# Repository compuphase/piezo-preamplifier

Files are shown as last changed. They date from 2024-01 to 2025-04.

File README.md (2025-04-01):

# Piezo Pickup Preamplifier
These are simple designs for high impedance preamplifiers. They are intended for
piezo pickups, and in particular for piezo bridge pickups for (nylon-stringed)
guitars. There is a single-channel and a dual-channel design.

The designs are in KiCad. PDFs with the schematics, and the Gerber files for the
PCBs are also provided.

## Single channel
This circuit was built for use with a Shadow SH097 bridge pickup. The pickup has
a capacitance of 680pF. Yet, input impedance of this preamplifier is *only*
1M&Omega;, because the basses were already quite pronounced.

It is a pretty classic opamp circuit. Amplification is fixed at 1&times;
&mdash;the circuit is only to adapt the impedance (piezo bridge pickups are
pretty loud already). The main feature of the circuit is that it is compact,
and especially narrow. The idea is to fit this preamplifier into a slot
immediately below the pickup.

The PDF with the schematic also shows the wiring for a TRS socket and battery;
these are not on the PCB, and technically not part of the circuit). The main
idea of the wiring is that the battery is connected only when the jack plug is
inserted. When the plug is pulled out of the instrument, the battery is disconnected.

## Dual channel
This circuit was built for the ARTEC PG-333 bridge pickup. The pickup connects two
piezo bridge pickups in parallel, where each pickup covers only three strings. For
use with this preamplifier, the two piezo segments have to be separated, and each
connected to a separate input of the preamplifer. Input impedance for each channel
is roughly 2M&Omega;.

I measured one of the piezo segments to have a capacitance of 580pF and the other
as 970pF &mdash;to my surprise. This being the case, you will want to position
the 580pF segment at the treble side, and the 970pF segment at the bass side of
the bridge.

The dual-channel circuit has two independent impedance converters, and a third
preamplifier to mix the outputs of the first stages. The balance of the "treble"
side relative to the "bass" side, can be adjusted with a trimmer pot.

The preamplifier has a "bass boost" filter that boosts the frequencies below
roughly 250 Hz by roughly 5 dB. The resonance chamber of a classical guitar has
a main resonant frequency at around 200 to 250 Hz, which is what the bass boost
emulates.

---

Copyright 2023-2025, CompuPhase, Thiadmer Riemersma<br>
This work is licensed under a Creative Commons Attribution-NonCommercial-ShareAlike 4.0 International License (https://creativecommons.org/licenses/by-nc-sa/4.0/).

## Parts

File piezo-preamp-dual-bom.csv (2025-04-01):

Reference | Value | Footprint | Qty | ProductNumber
C1,C2,C5 | 220n | VisualPlace:0603 | 3
C3,C4 | 68p | VisualPlace:0603 | 2
C6 | 22n | VisualPlace:0603 | 1
C7,C9,C10 | 1u | VisualPlace:0603 | 3
C8 | 4u7 | VisualPlace:0805 | 1
R1,R2 | 2M2 | VisualPlace:0603 | 2
R3,R4,R5,R6,R10,R11,R12,R15 | 100k | VisualPlace:0603 | 8
R7,R8 | 470k | VisualPlace:0603 | 2
R9,R13 | 22k | VisualPlace:0603 | 2
RV2 | 20k | TrimPots:TC42 | 1 | 3312J-1-203E
U1,U2,U3 | OPA323 | VisualPlace:SOT353 | 3 | OPA323IDCKR

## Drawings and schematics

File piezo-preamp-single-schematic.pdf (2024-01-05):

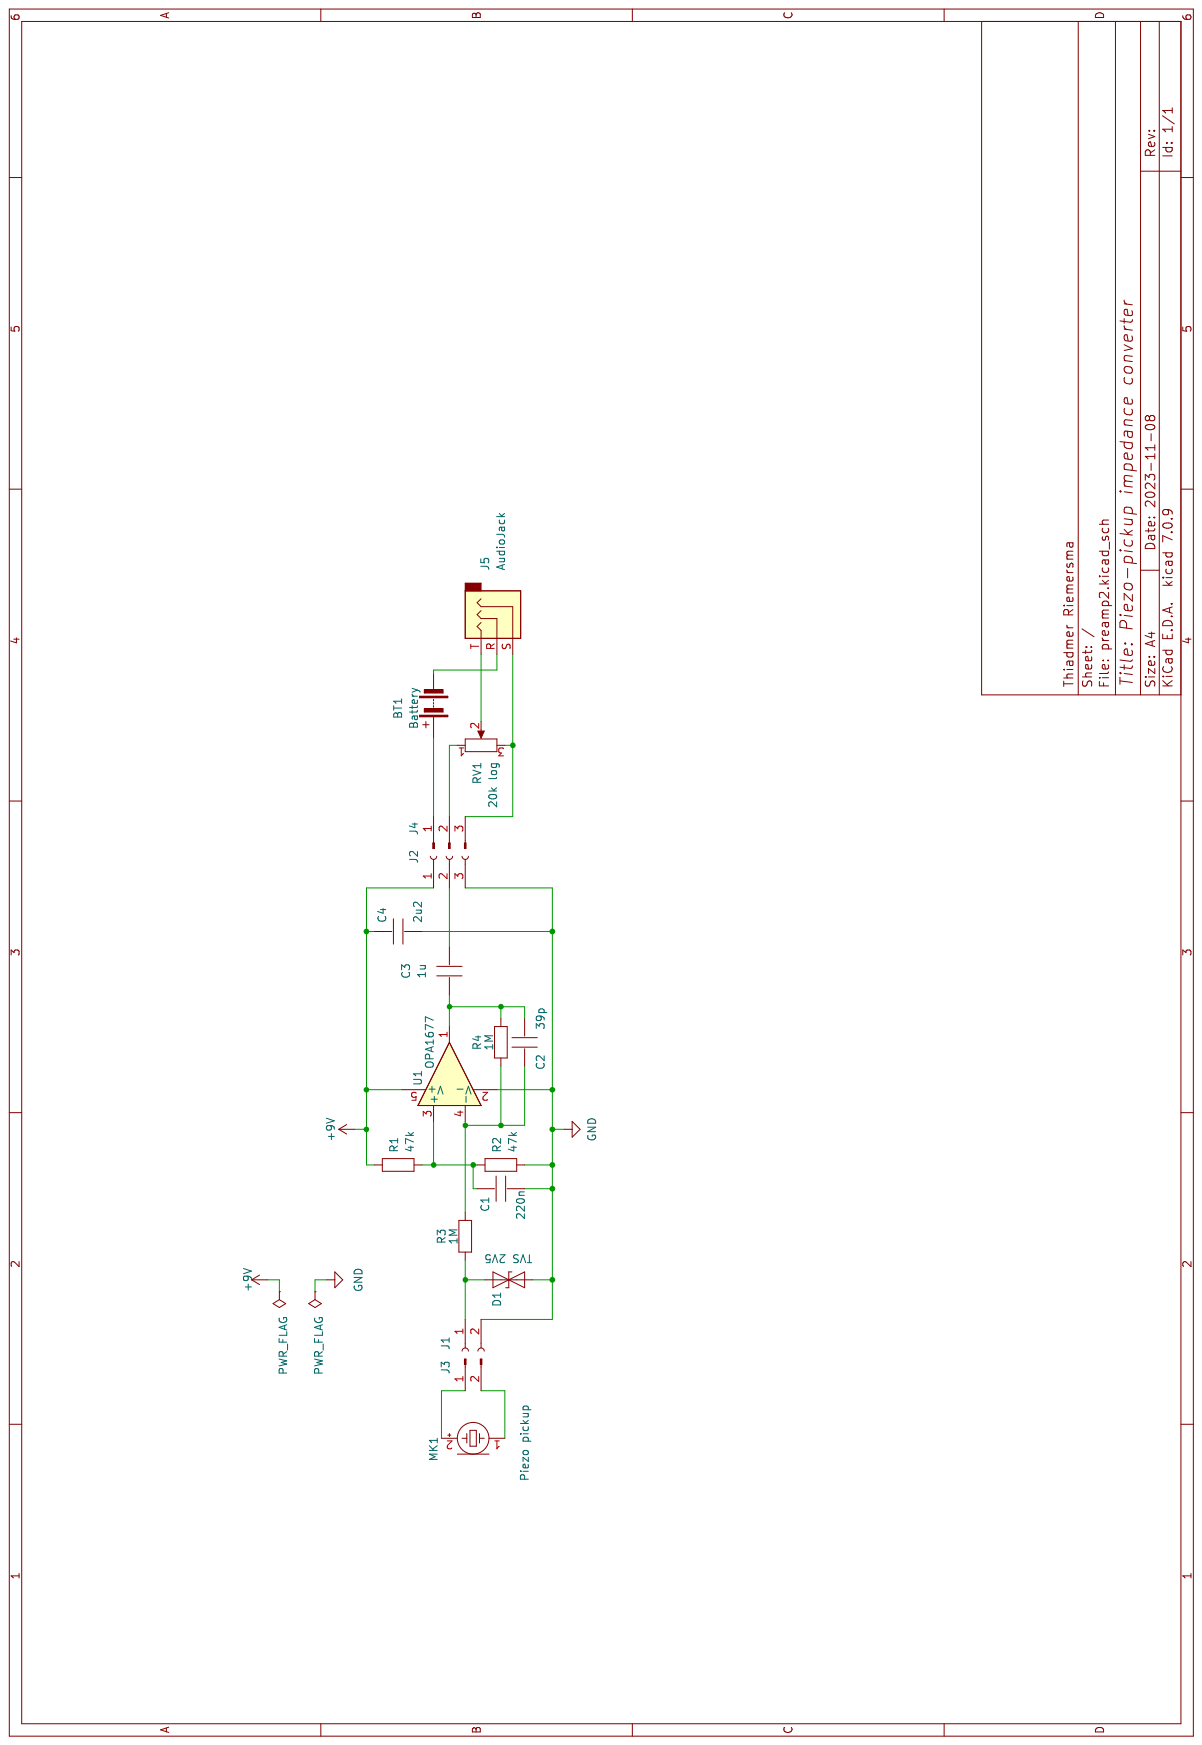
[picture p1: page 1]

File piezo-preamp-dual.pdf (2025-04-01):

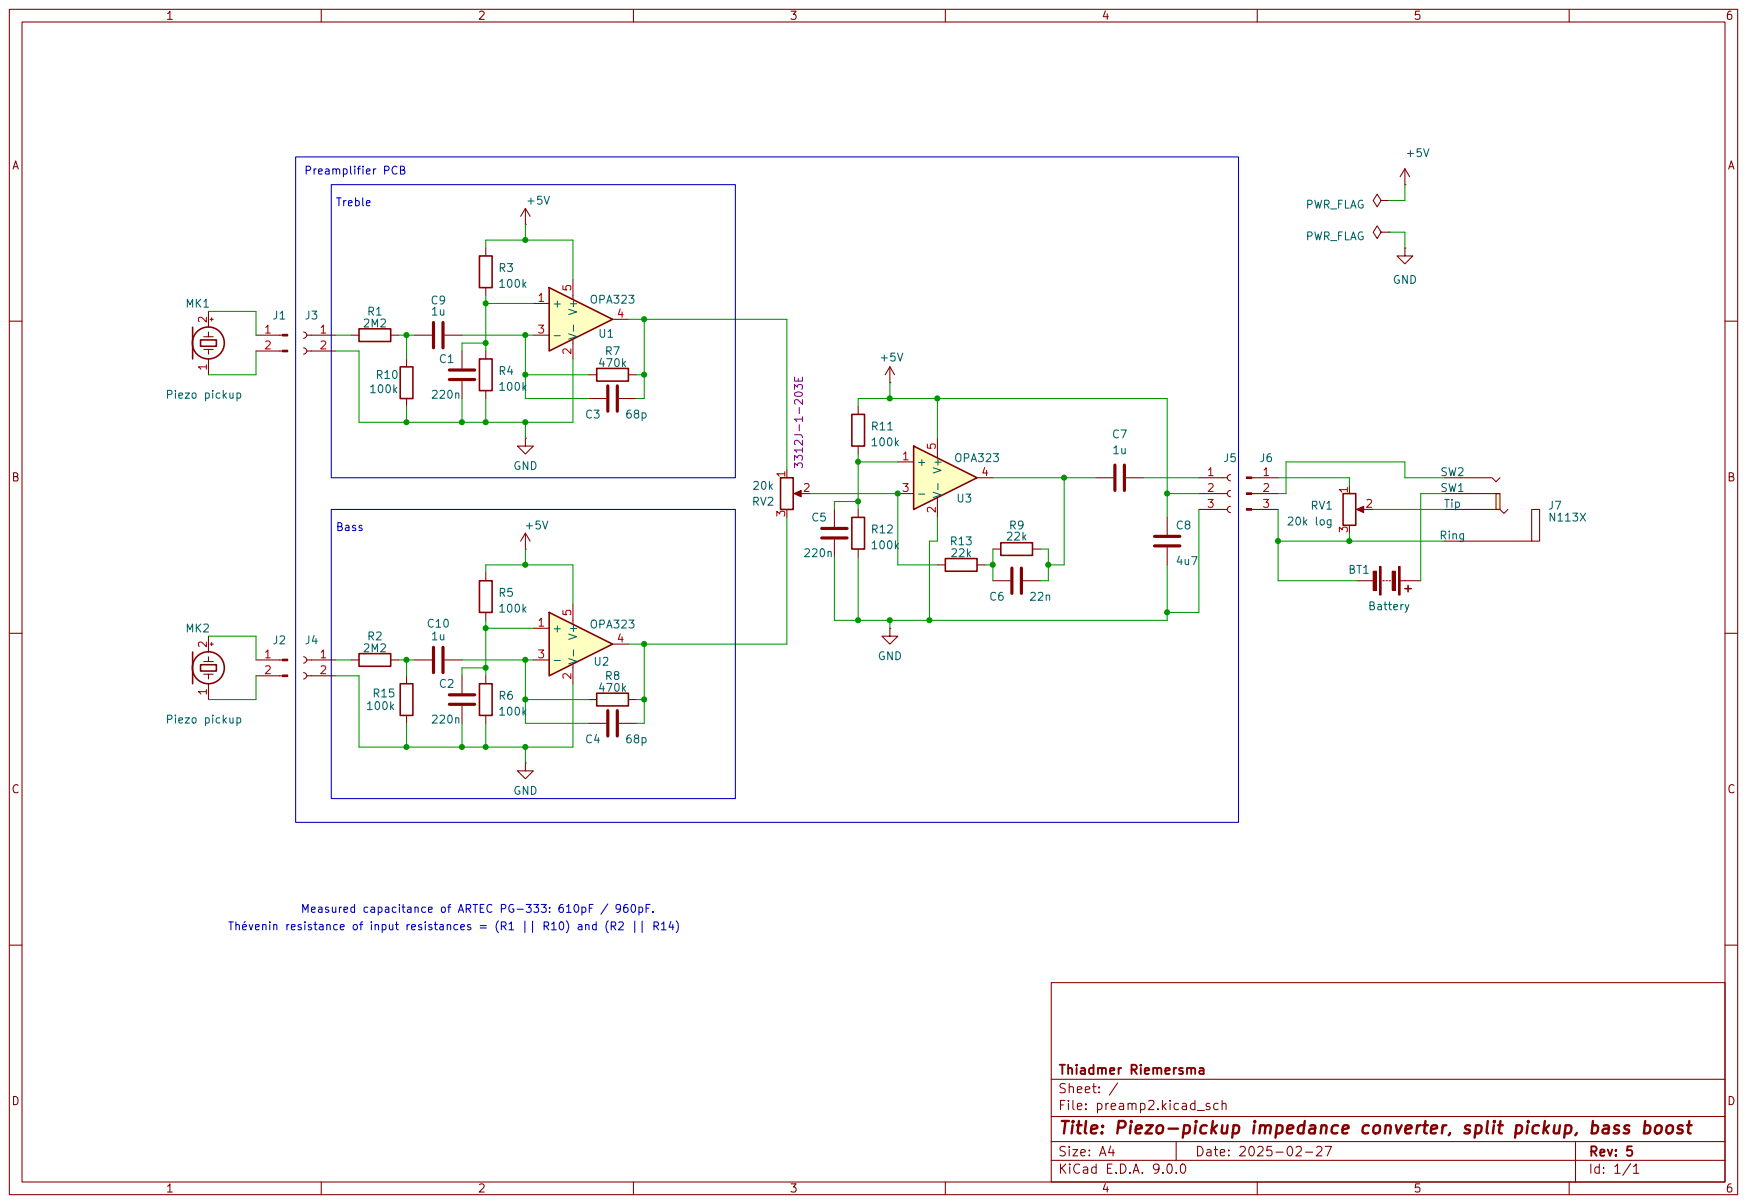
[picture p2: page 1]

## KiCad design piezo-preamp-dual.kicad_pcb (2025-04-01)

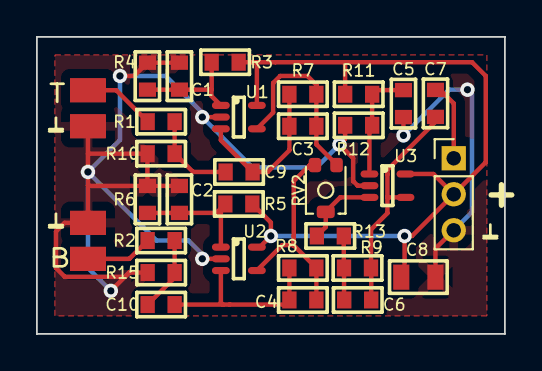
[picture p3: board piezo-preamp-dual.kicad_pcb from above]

Board: 2 copper layers, 26.0 x 16.5 mm, 31 parts (0 on the bottom side), 17 nets.

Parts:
C1, C2, C5: 220n; 0603
C3, C4: 68p; 0603
C6: 22n; 0603
C7: 1u; 0603
C8: 4u7; 0805
C9, C10: 100k; 0603
J3, J4: piezo; PinHeader_1x02_P2.00mm_Vertical
J5: output; PinHeader_1x03_P2.00mm_Vertical
R1, R2: 2M2; 0603
R3, R4, R5, R6, R10, R11, R12, R15: 100k; 0603
R7, R8: 470k; 0603
R9, R13: 22k; 0603
RV2: 20k; TC42
U1, U2, U3: OPA323; SOT353

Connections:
+5V: C8.1, J5.2, R3.1, R5.1, R11.1, U1.5 (V+), U2.5 (V+), U3.5 (V+)
GND: C1.2, C2.2, C5.2, C8.2, J3.2, J4.2, J5.3, R4.2, R6.2, R10.2, R12.2, R15.2, U1.2 (V-), U2.2 (V-), U3.2 (V-)
unnamed: C3.2, R7.2, RV2.1, U1.4
unnamed: C4.2, R8.2, RV2.3, U2.4
unnamed: C6.1, R9.1, R13.2
unnamed: C6.2, C7.1, R9.2, U3.4
unnamed: J3.1, R1.1
unnamed: J4.1, R2.1
unnamed: C7.2, J5.1
unnamed: C9.1, R1.2, R10.1
unnamed: C10.1, R2.2, R15.1
unnamed: C1.1, R3.2, R4.1, U1.1 (+)
unnamed: C3.1, C9.2, R7.1, U1.3 (-)
unnamed: C2.1, R5.2, R6.1, U2.1 (+)
unnamed: C4.1, C10.2, R8.1, U2.3 (-)
unnamed: C5.1, R11.2, R12.1, U3.1 (+)
unnamed: R13.1, RV2.2, U3.3 (-)

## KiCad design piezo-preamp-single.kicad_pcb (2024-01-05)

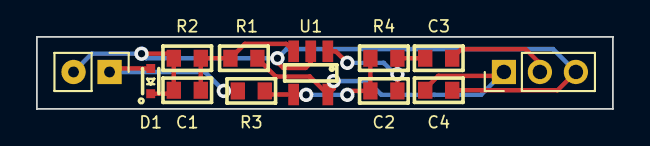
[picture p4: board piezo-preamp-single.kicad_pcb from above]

Board: 2 copper layers, 32.0 x 4.0 mm, 12 parts (0 on the bottom side), 7 nets.

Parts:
C1, C3, C4: 1u; 0603
C2: 10p; 0603
D1: TVS 6V; SOD523
J1: piezo; PinHeader_1x02_P2.00mm_Vertical
J2: output; PinHeader_1x03_P2.00mm_Vertical
R1, R2: 22k; 0603
R3, R4: 820k; 0603
U1: OPA1677; SOT23-5

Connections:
+9V: C4.1, J2.1, R1.1, U1.5 (V+)
GND: C1.2, C4.2, D1.1 (A1), J1.2, J2.3, R2.2, U1.2 (V-)
unnamed: C2.2, C3.1, R4.2, U1.1
unnamed: D1.2 (A2), J1.1, R3.1
unnamed: C3.2, J2.2
unnamed: C1.1, R1.2, R2.1, U1.3 (+)
unnamed: C2.1, R3.2, R4.1, U1.4 (-)

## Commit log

2023-12-25 Add PDF of schematic.
2023-12-27 Tweaked some component values.
    [preamp2.kicad_sch]
2023-12-27 Tweaked some component values, again.
    [preamp2.kicad_sch]
2023-12-27 Update README.md
    Correction in the description for the input impedance and frequency cut-off point.
2024-01-05 A few more tweaks in components, after more measurements.
    [preamp2.kicad_pcb, preamp2.kicad_sch]
2024-01-19 Rename design files for single-channel amplifier.
    [piezo-preamp-single.kicad_pcb, piezo-preamp-single.kicad_sch]
2024-01-19 Rename Gerber files for single-channel piezo amplifier.
    [piezo-preamp-job.gbrjob, piezo-preamp-single-B_Cu.gbr, piezo-preamp-single-B_Mask.gbr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]
2024-01-19 Add dual-channel piezo preamplifier.
    [piezo-preamp-dual-B_Cu.gbr, piezo-preamp-dual-B_Mask.gbr, piezo-preamp-dual-Edge_Cuts.gbr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]
2024-01-31 The TVS diodes were removed from the "dual-channel" design. The PCB is slighly smaller as a result.
    The parasitic capacitance of the TVS diodes had a negative effect on the sound. In addition, they were redundant; the inputs of the OPA1677 are already protected against overvoltage, so the 1 MOhm re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
    [piezo-preamp-dual-B_Cu.gbr, piezo-preamp-dual-B_Mask.gbr, piezo-preamp-dual-Edge_Cuts.gbr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]
2024-07-14 Added bass-boost filter (dual-channel preamp only). Added Bill-Of-Materials file. Fixed PDF of the schematic (turned out to be unreadable).
    [piezo-preamp-dual-bom.csv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]
2025-04-01 Reduce (peak) voltage of the piezo pick-ups, to avoid saturatating the opamps. Switch opamps to OPA323, to avoid clamping diodes on input. Higher input impedance.
    [piezo-preamp-dual-bom.csv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]
